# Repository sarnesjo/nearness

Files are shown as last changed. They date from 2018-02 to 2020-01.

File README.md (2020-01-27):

# Nearness

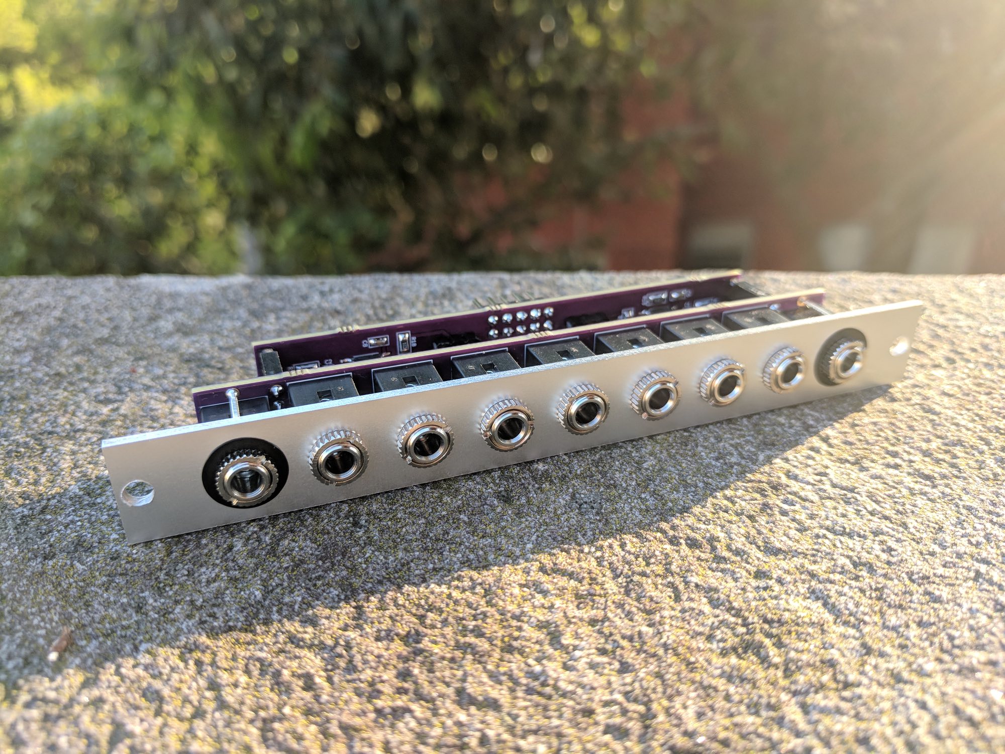
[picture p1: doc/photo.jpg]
Nearness


Minimal panning mixer for the Eurorack modular synthesizer system. Seven inputs, two outputs. The closer an input is to an output, the greater its influence on it. 3HP.

A product of the [*llllllll*](https://llllllll.co/t/prototyping-nearness-a-minimal-panning-mixer-module/8330) community.

## PCB

The [pcb](pcb) directory contains the schematic and PCB layout as a KiCad 5 project.

For convenience, the PCBs are available from OSH Park ([front](https://oshpark.com/shared_projects/fqV5h7cJ), [back](https://oshpark.com/shared_projects/oqCUYtxb)).

## Panel

The [panel](panel) directory contains a basic panel layout in SVG format, for use with a laser cutter or CNC machine.

Alternative panel designs are available:

- Joshua Goran ([files](https://llllllll.co/t/prototyping-nearness-a-minimal-panning-mixer-module/8330/66), [photos](https://llllllll.co/t/prototyping-nearness-a-minimal-panning-mixer-module/8330/92))
- Ben Moren ([repo](https://github.com/bmoren/nearness-black-gold-panel), [photos](https://llllllll.co/t/prototyping-nearness-a-minimal-panning-mixer-module/8330/112))

## Build guide

1. Start with the surface-mount components. Mind the orientation of the ICs and diodes.
2. Then do the pin headers.
3. Then the jacks.

## License

[CC BY-SA 4.0](http://creativecommons.org/licenses/by-sa/4.0/)

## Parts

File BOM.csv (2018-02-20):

Reference | Qty | Description | Value | Package | Digikey # | Mouser # | Notes
U1, U2 | 2 | IC, LME49720 |  | SOIC-8 | LME49720MAX/NOPBCT-ND | 926-LME49720MAX/NOPB
D1, D2 | 2 | Diode, 1N5819HW |  | SOD-123 | 1N5819HW-FDICT-ND | 621-1N5819HW-F
C1, C2 | 2 | Capacitor, ceramic, C0G/NP0 | 22p | 0603 | 490-9685-1-ND | 81-GRM185C1H220FA01J
C3, C4 | 2 | Capacitor, ceramic | 22u | 0805 | 490-10749-1-ND | 81-GRM21BR61E226ME4L
C5, C6, C7, C8 | 4 | Capacitor, ceramic | 100n | 0603 | 490-9691-1-ND | 81-GRM188R71E104JA1J
R1, R14, R15, R16, R17, R18, R19, R20, R21, R22 | 10 | Resistor, thin film, 0.1% | 100k | 0805 | P100KDACT-ND | 667-ERA-6AEB104V
R2, R13 | 2 | Resistor, thick film, 1% | 1M69 | 0805 | P1.69BTCT-ND | 667-ERJ-6ENF1694V
R3, R12 | 2 | Resistor, thin film, 0.1% | 102k | 0805 | P102KDACT-ND | 667-ERA-6AEB1023V
R4, R11 | 2 | Resistor, thin film, 0.1% | 442k | 0805 | P442KDACT-ND | 667-ERA-6AEB4423V
R5, R10 | 2 | Resistor, thin film, 0.1% | 113k | 0805 | P113KDACT-ND | 667-ERA-6AEB1133V
R6, R9 | 2 | Resistor, thin film, 0.1% | 215k | 0805 | P215KDACT-ND | 667-ERA-6AEB2153V
R7, R8 | 2 | Resistor, thin film, 0.1% | 140k | 0805 | P140KDACT-ND | 667-ERA-6AEB1403V
R23, R24 | 2 | Resistor, thin film, 0.1% | 1k | 0805 | P1.0KDACT-ND | 667-ERA-6AEB102V
P1, P2 | 2 | Pin header, female, 1x5 |  |  |  |  | http://www.taydaelectronics.com/5-pin-2-54-mm-single-row-female-pin-header.html
P3, P4 | 2 | Pin header, male, 1x5 |  |  |  |  | http://www.taydaelectronics.com/40-pin-2-54-mm-single-row-pin-header-strip.html
P5, P6 | 2 | Pin header, male, right angle, 1x3 |  |  |  |  | http://www.taydaelectronics.com/40-pin-2-54-mm-angle-single-row-pin-header.html
P7 | 1 | Pin header, male, 2x5 |  |  |  |  | http://www.taydaelectronics.com/2x40-pin-2-54-mm-double-row-pin-header-strip.html
J1, J2, J3, J4, J5, J6, J7, J8, J9 | 9 | Jack, PJ301M-12 |  |  |  |  | https://www.thonk.co.uk/shop/3-5mm-jacks/
 | 2 | Jumper |  |  |  |  | http://www.taydaelectronics.com/mini-jumper-2-54mm-gold-plated-closed-cover.html

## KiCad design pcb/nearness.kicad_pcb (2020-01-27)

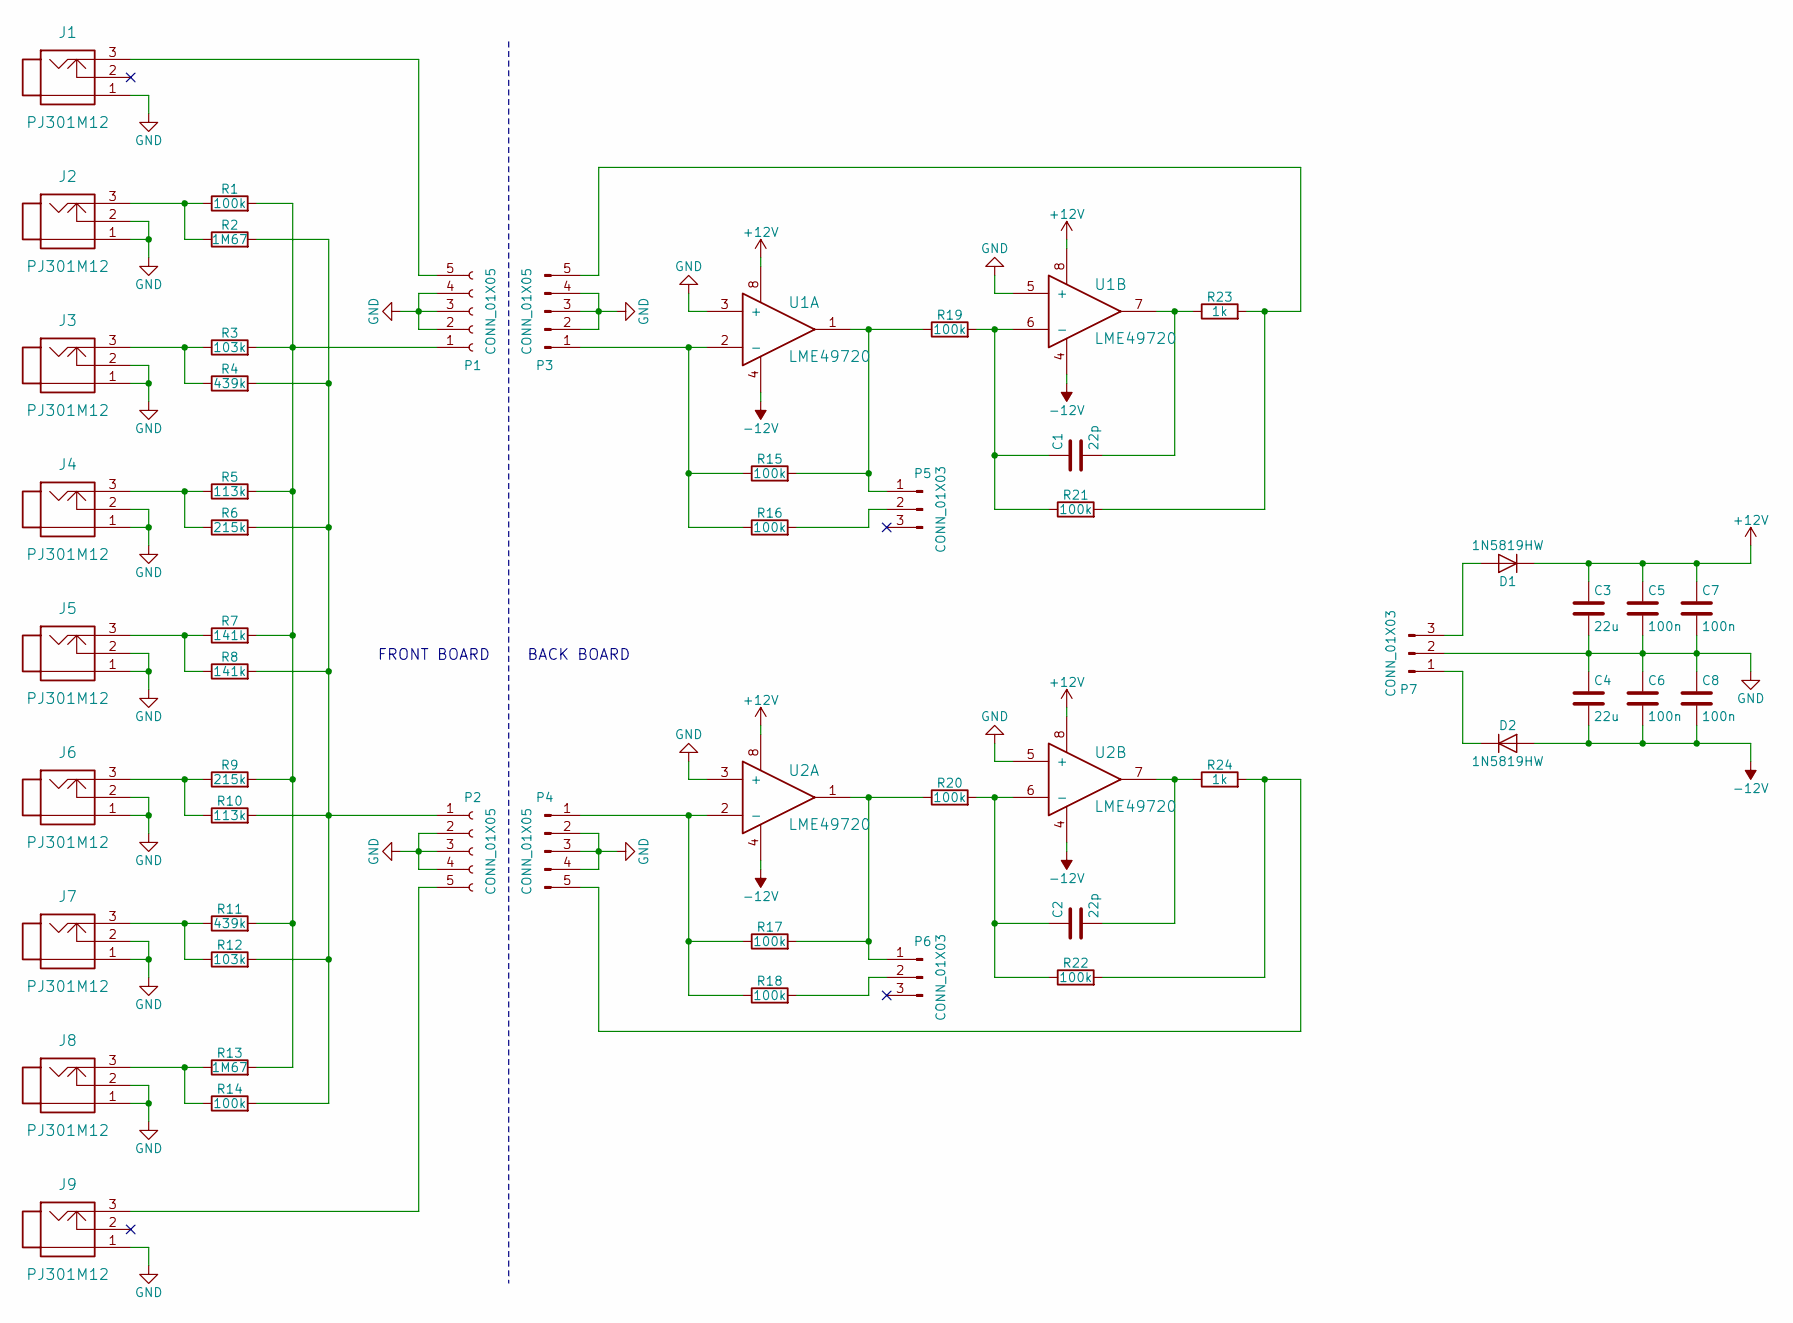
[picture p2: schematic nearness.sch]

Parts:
C1, C2: 22p; 0603
C3, C4: 22u; 0805
C5, C6, C7, C8: 100n; 0603
D1, D2: 1N5819HW; SOD-123
J1, J2, J3, J4, J5, J6, J7, J8, J9: PJ301M12
P1, P2, P3, P4: CONN_01X05; Pin_1x5
P5, P6: CONN_01X03; Pin_1x3
P7: CONN_01X03; Eurorack_2x5
R1, R14, R15, R16, R17, R18, R19, R20, R21, R22: 100k; 0805
R2, R13: 1M67; 0805
R3, R12: 103k; 0805
R4, R11: 439k; 0805
R5, R10: 113k; 0805
R6, R9: 215k; 0805
R7, R8: 141k; 0805
R23, R24: 1k; 0805
U1, U2: LME49720; SOIC-8

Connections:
+12V: C3.1, C5.1, C7.1, D1.1 (K), U1.8, U2.8
-12V: C4.2, C6.2, C8.2, D2.2 (A), U1.4, U2.4
GND: C3.2, C4.1, C5.2, C6.1, C7.2, C8.1, J1.1, J2.1, J2.2, J3.1, J3.2, J4.1, J4.2, J5.1, J5.2, J6.1, J6.2, J7.1, J7.2, J8.1, J8.2, J9.1, P1.2, P1.3, P1.4, P2.2, P2.3, P2.4, P3.2, P3.3, P3.4, P4.2, P4.3, P4.4, P7.2, U1.3 (+), U1.5 (+), U2.3 (+), U2.5 (+)
unnamed: C1.1, R19.2, R21.1, U1.6 (-)
unnamed: C1.2, R23.1, U1.7
unnamed: C2.1, R20.2, R22.1, U2.6 (-)
unnamed: C2.2, R24.1, U2.7
unnamed: D1.2 (A), P7.3
unnamed: D2.1 (K), P7.1
unnamed: J1.3, P1.5
unnamed: J2.3, R1.1, R2.1
unnamed: J3.3, R3.1, R4.1
unnamed: J4.3, R5.1, R6.1
unnamed: J5.3, R7.1, R8.1
unnamed: J6.3, R9.1, R10.1
unnamed: J7.3, R11.1, R12.1
unnamed: J8.3, R13.1, R14.1
unnamed: J9.3, P2.5
unnamed: P1.1, R1.2, R3.2, R5.2, R7.2, R9.2, R11.2, R13.2
unnamed: P2.1, R2.2, R4.2, R6.2, R8.2, R10.2, R12.2, R14.2
unnamed: P3.1, R15.1, R16.1, U1.2 (-)
unnamed: P3.5, R21.2, R23.2
unnamed: P4.1, R17.1, R18.1, U2.2 (-)
unnamed: P4.5, R22.2, R24.2
unnamed: P5.1, R15.2, R19.1, U1.1
unnamed: P5.2, R16.2
unnamed: P6.1, R17.2, R20.1, U2.1
unnamed: P6.2, R18.2

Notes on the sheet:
FRONT BOARD
BACK BOARD

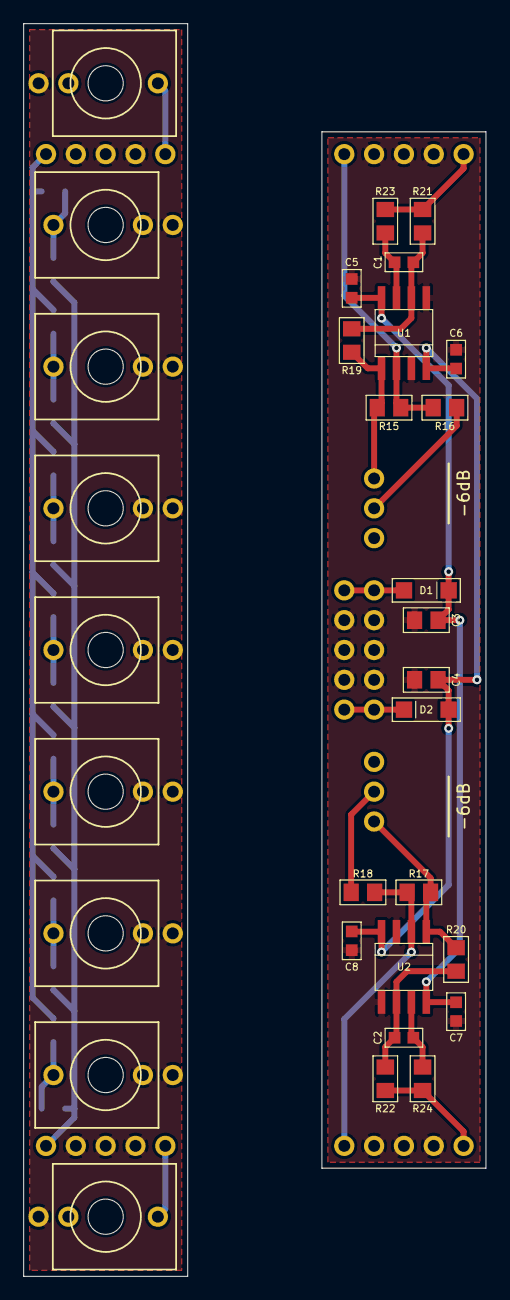
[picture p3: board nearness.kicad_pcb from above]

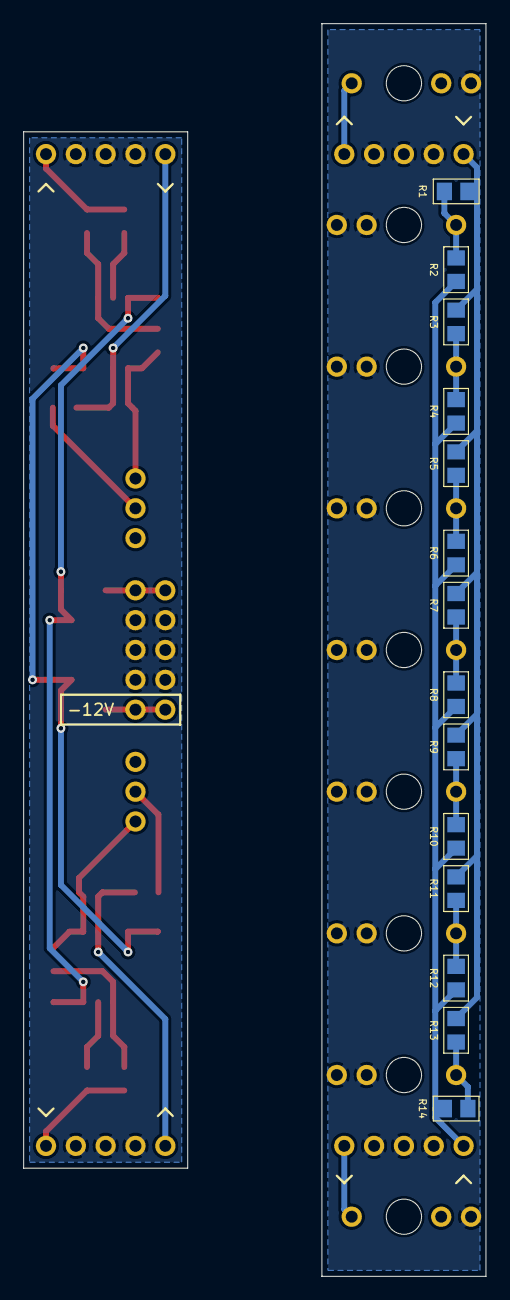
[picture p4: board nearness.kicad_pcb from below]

Board: 2 copper layers, 39.4 x 106.7 mm, 52 parts (15 on the bottom side), 28 nets.

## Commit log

2018-02-20 Import files
    [BOM.csv, nearness.kicad_pcb, nearness.sch]
2020-01-27 Upgrade project to KiCad 5
    Upgrade project, library, schematic, and PCB files to KiCad 5. Remap
    symbols to the Device and Connector libraries, using different symbols
    for male and female pin headers. Re-annotate schematic. Re-fill zones.
    Ignore KiCad 5 backup and cache files.
    [nearness.kicad_pcb, nearness.sch]
